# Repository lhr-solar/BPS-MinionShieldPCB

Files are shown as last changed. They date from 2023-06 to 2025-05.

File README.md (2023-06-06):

# BPS-MinionShieldPCB
TODO: Update with useful information

## Components
[Mouser cart]
https://www.mouser.com/ProjectManager/ProjectDetail.aspx?AccessID=0a4c326737

Note: The PADP-24V-1-S connector is not available on mouser, but may be purchased through digikey from this link
https://www.digikey.com/en/products/detail/jst-sales-america-inc/PADP-24V-1-S/1300227

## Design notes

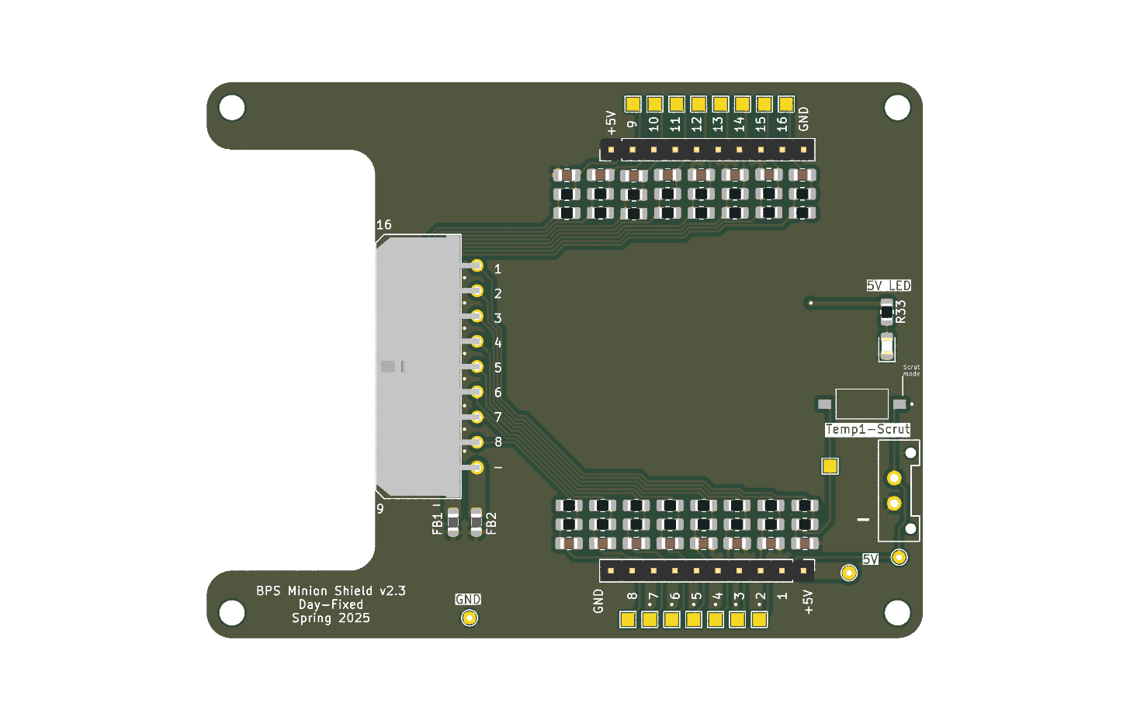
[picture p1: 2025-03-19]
docs/render.png

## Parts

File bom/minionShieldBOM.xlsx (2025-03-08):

Reference | Value | Datasheet | Footprint | Qty | DNP | p/n
C1,C2,C3,C4,C5,C6,C7,C8,C9,C10,C11,C12,C13,C14,C15,C16 | 47nF | https://www.mouser.com/ProductDetail/YAGEO/CC0805JRX7R9BB473?qs=AgBp2OyFlx%252BtTbCMaJ6C1Q%3D%3D | Capacitor_SMD:C_0805_2012Metric_Pad1.18x1.45mm_HandSolder | 16 |  | CC0805JRX7R9BB473
FB1,FB2 | 2.2k | https://www.digikey.com/en/products/detail/laird-signal-integrity-products/HZ0805B222R-10/1236418 | Inductor_SMD:L_0805_2012Metric_Pad1.05x1.20mm_HandSolder | 2 |  | HZ0805B222R-10
J3 | Conn_01x02 | ~ | UTSVT_Connectors:Molex_MicroFit3.0_1x2xP3.00mm_PolarizingPeg_Vertical | 1 |  | 436500227
J4 | Conn_02x09_Counter_Clockwise | ~ | Connector_Molex:Molex_Micro-Fit_3.0_43045-1800_2x09_P3.00mm_Horizontal | 1 |  | 43045-1800
PowerLED1 | Green | https://www.mouser.com/ProductDetail/710-150080VS75000 | LED_SMD:LED_0805_2012Metric_Pad1.15x1.40mm_HandSolder | 1 |  | 150080VS75000
R1,R3,R5,R7,R9,R11,R13,R15,R17,R19,R21,R23,R25,R27,R29,R31 | 4.7k | https://www.mouser.com/ProductDetail/603-RT0805FRE074K7L | Resistor_SMD:R_0805_2012Metric_Pad1.20x1.40mm_HandSolder | 16 |  | RT0805FRE074K7L
R2,R4,R6,R8,R10,R12,R14,R16,R18,R20,R22,R24,R26,R28,R30,R32 | 10k | https://www.mouser.com/ProductDetail/603-RT0805FRE0710KL | Resistor_SMD:R_0805_2012Metric_Pad1.20x1.40mm_HandSolder | 16 |  | RT0805FRE0710KL
R33 | 1.2k | https://www.mouser.com/ProductDetail/603-RT0805FRE071K2L | Resistor_SMD:R_0805_2012Metric_Pad1.20x1.40mm_HandSolder | 1 |  | RT0805FRE071K2L
SW1 | SW_DIP_x01 | ~ | MinionShield:DS04254201BKSMT | 1 |  | DS04-254-2-01BK-SMT

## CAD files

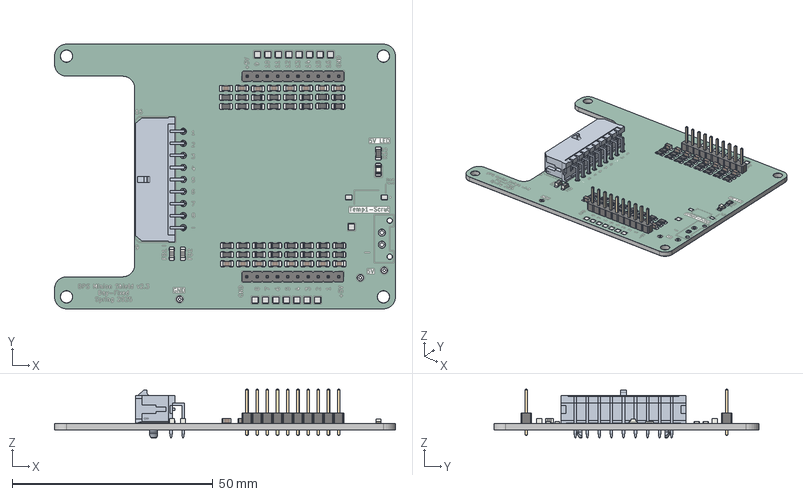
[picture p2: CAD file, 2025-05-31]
docs/renderBoard.step
85.0 x 66.0 x 12.2 mm
PinHeader_1x10_P2.54mm_Vertical x 2
R_0805_2012Metric x 33
C_0805_2012Metric x 16
L_0805_2012Metric x 2
LED_0805_2012Metric
BPS-MinionShield_copper
BPS-MinionShield_pad
BPS-MinionShield_via
BPS-MinionShield_silkscreen
BPS-MinionShield_soldermask
BPS-MinionShield_PCB

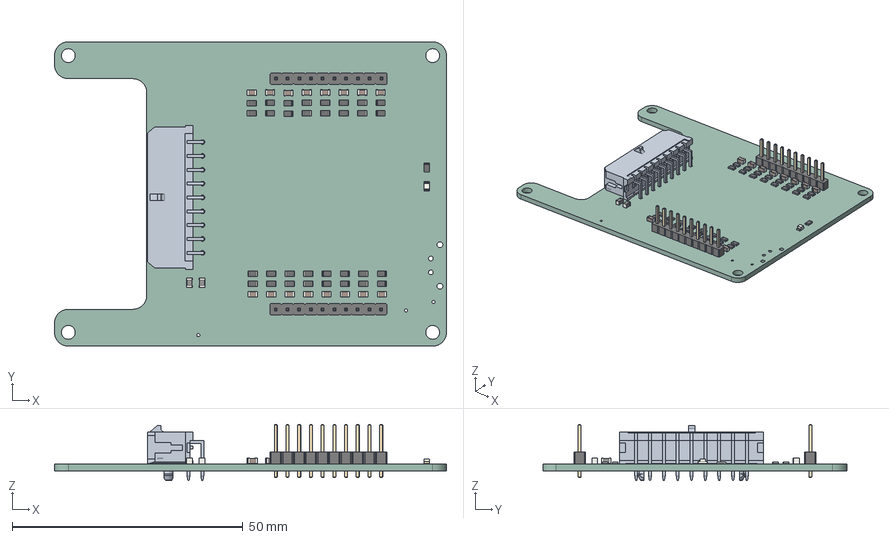
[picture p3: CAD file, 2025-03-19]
docs/board.step
85.0 x 66.0 x 12.2 mm
PinHeader_1x10_P2.54mm_Vertical x 2
R_0805_2012Metric x 33
C_0805_2012Metric x 16
L_0805_2012Metric x 2
LED_0805_2012Metric
BPS-MinionShield_PCB

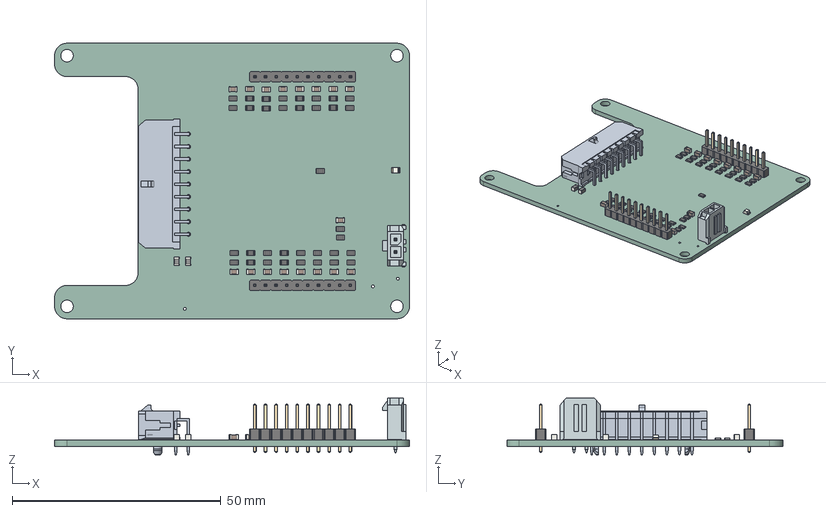
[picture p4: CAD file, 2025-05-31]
minion.step
85.0 x 66.0 x 13.6 mm
PinHeader_1x10_P2.54mm_Vertical x 2
R_0805_2012Metric x 35
C_0805_2012Metric x 17
L_0805_2012Metric x 2
LED_0805_2012Metric
BPS-MinionShield_PCB

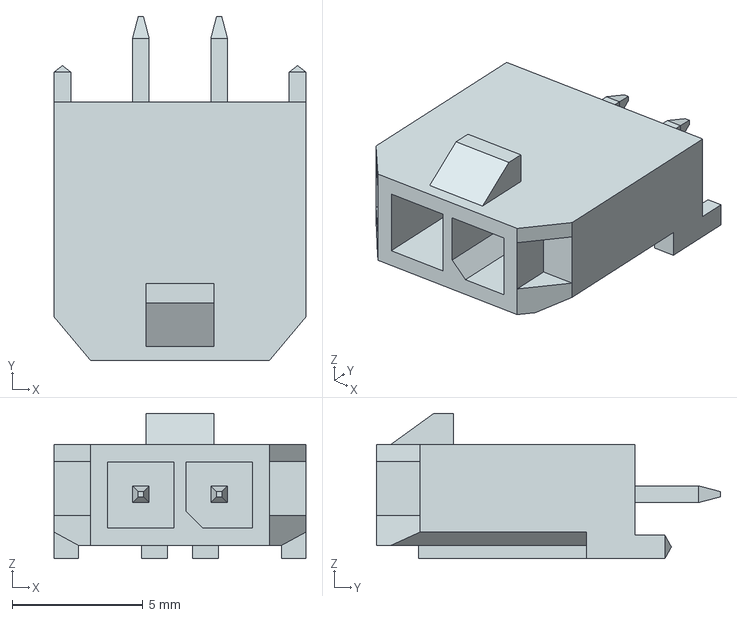
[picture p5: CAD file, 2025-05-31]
436500227.stp
9.65 x 13.2 x 5.57 mm

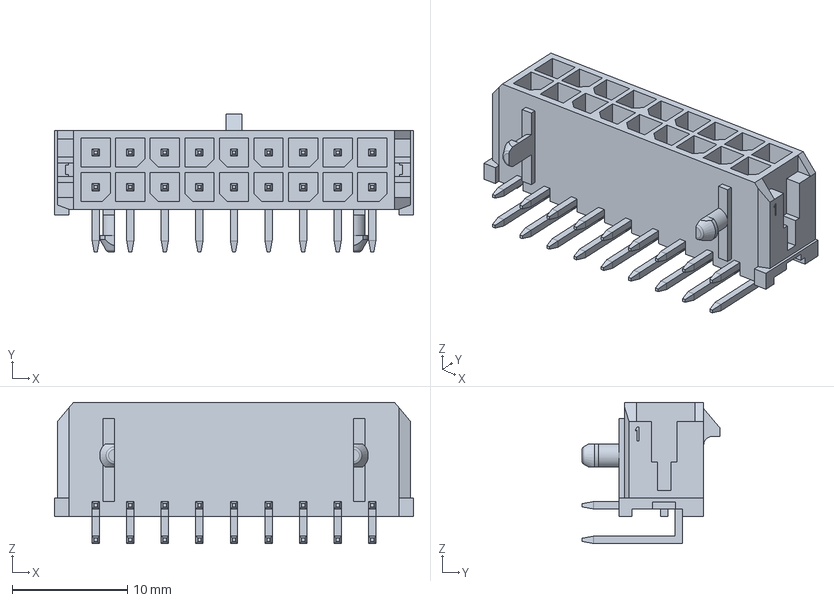
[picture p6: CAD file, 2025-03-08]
0430451800.stp
31.1 x 11.9 x 12.2 mm

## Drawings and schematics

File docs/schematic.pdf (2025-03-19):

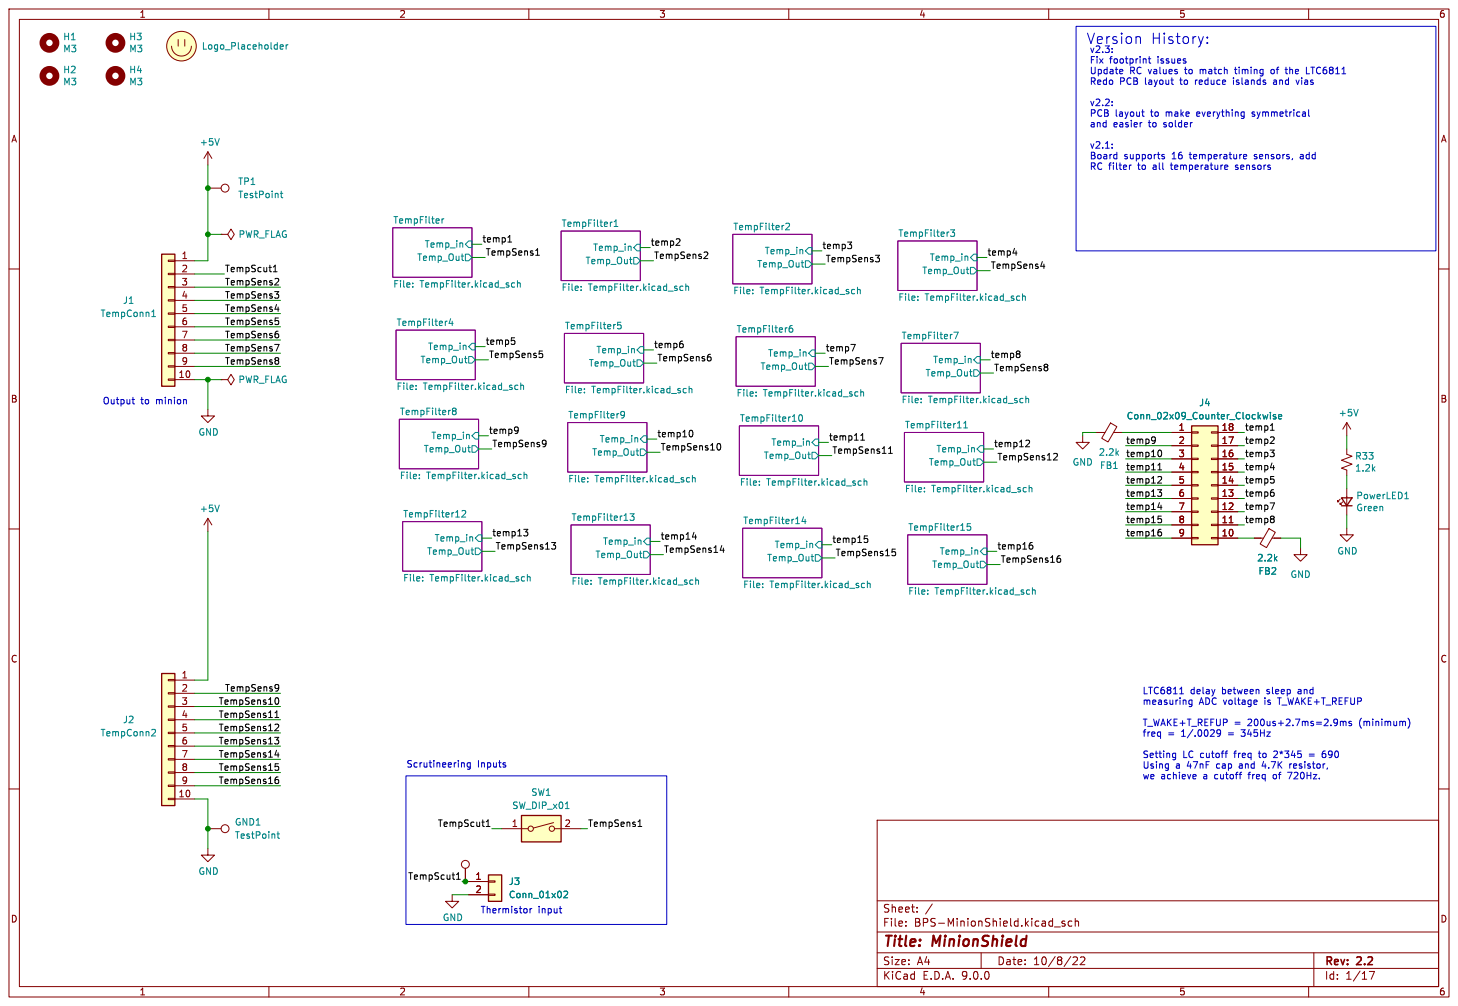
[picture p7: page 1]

File: BPS-MinionShield.kicad_sch Sheet: /
Id: 1/17 Title: MinionShield

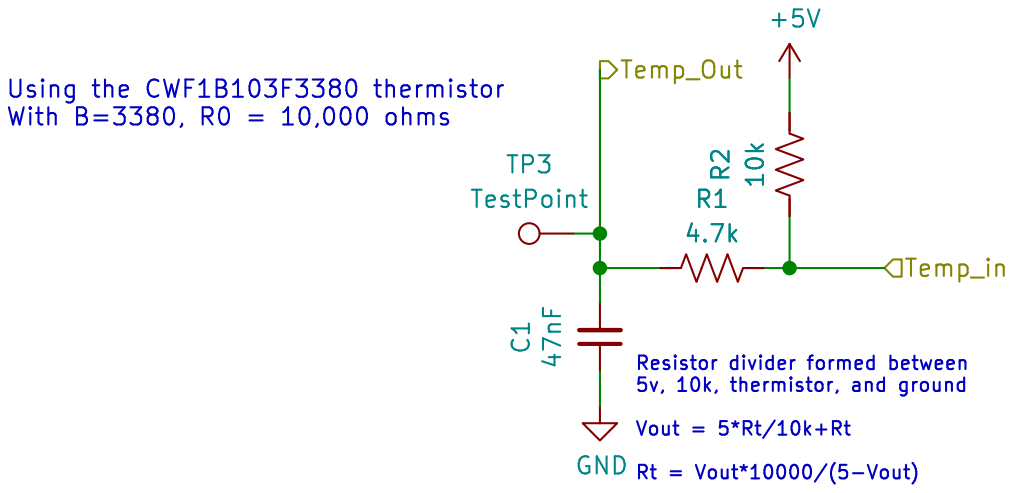
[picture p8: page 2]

Id: 2/17 Title: File: TempFilter.kicad_sch Sheet: /TempFilter/

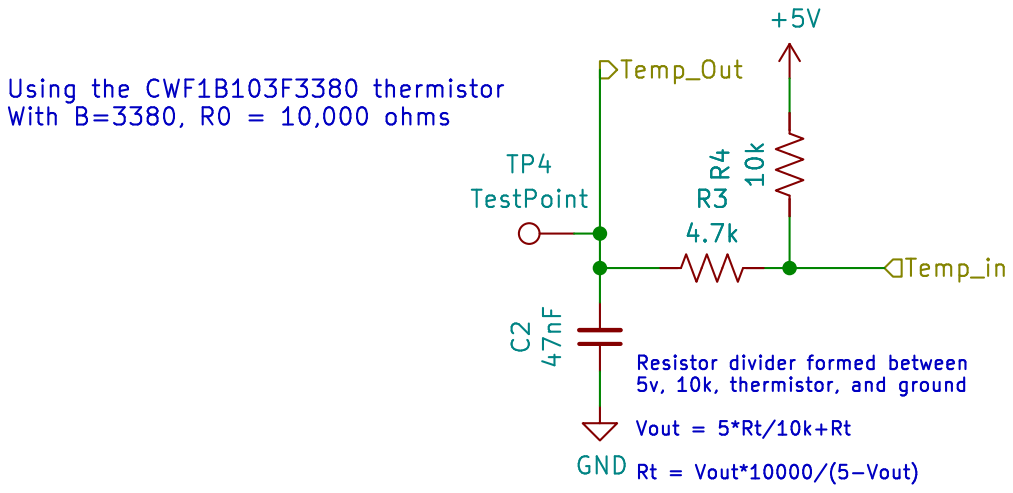
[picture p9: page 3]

Id: 3/17 Title: File: TempFilter.kicad_sch Sheet: /TempFilter1/

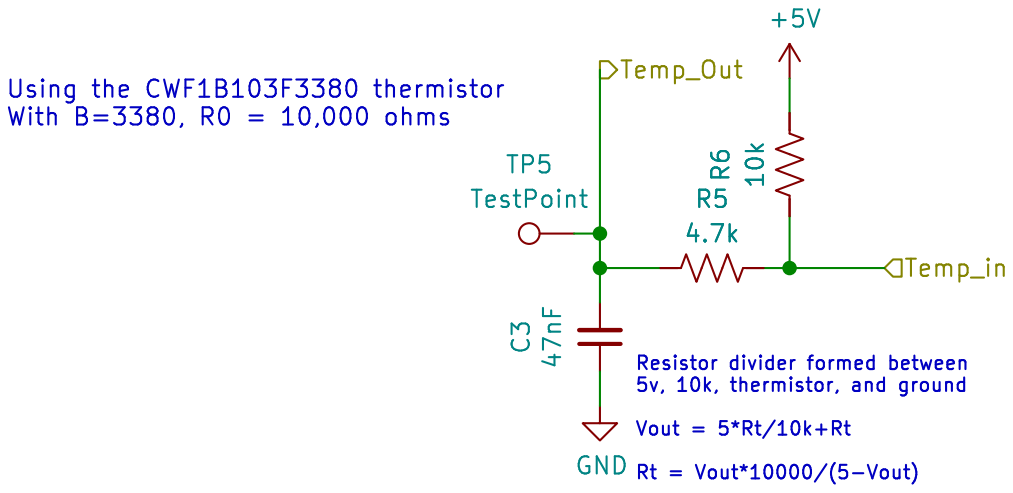
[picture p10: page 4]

Id: 4/17 Title: File: TempFilter.kicad_sch Sheet: /TempFilter2/

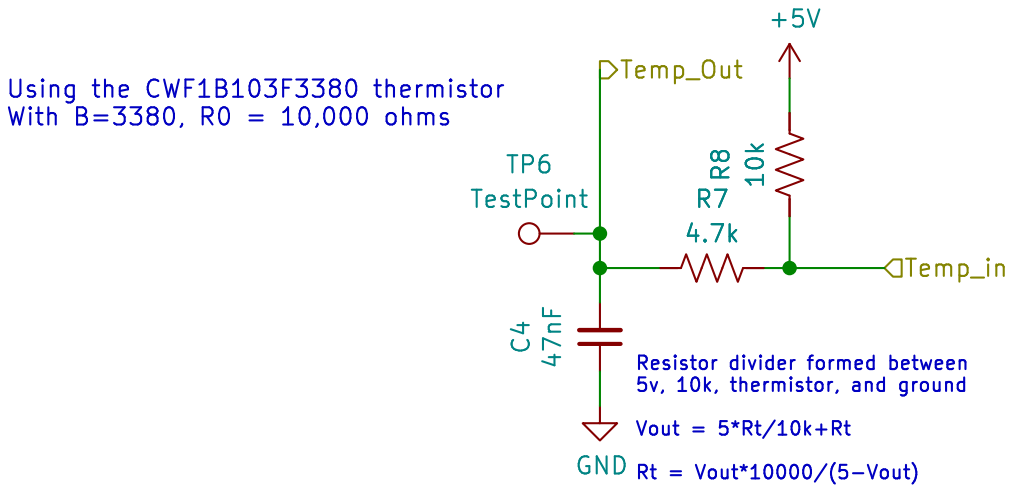
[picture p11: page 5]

Id: 5/17 Title: File: TempFilter.kicad_sch Sheet: /TempFilter3/

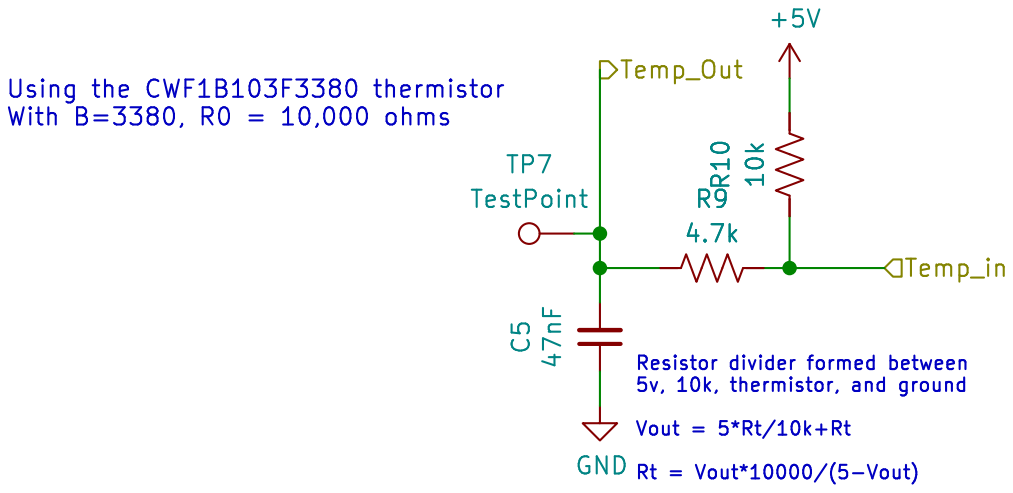
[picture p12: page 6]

Id: 6/17 Title: File: TempFilter.kicad_sch Sheet: /TempFilter4/

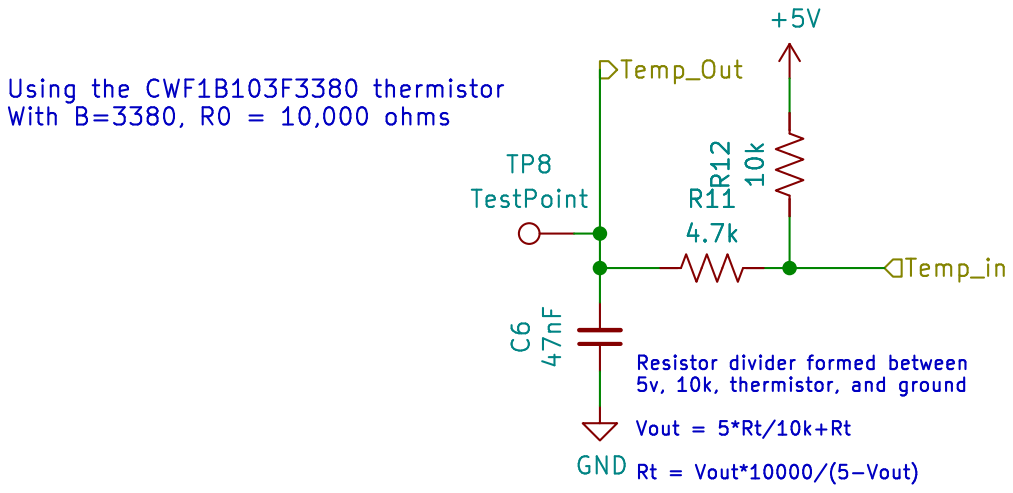
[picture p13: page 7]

Id: 7/17 Title: File: TempFilter.kicad_sch Sheet: /TempFilter5/

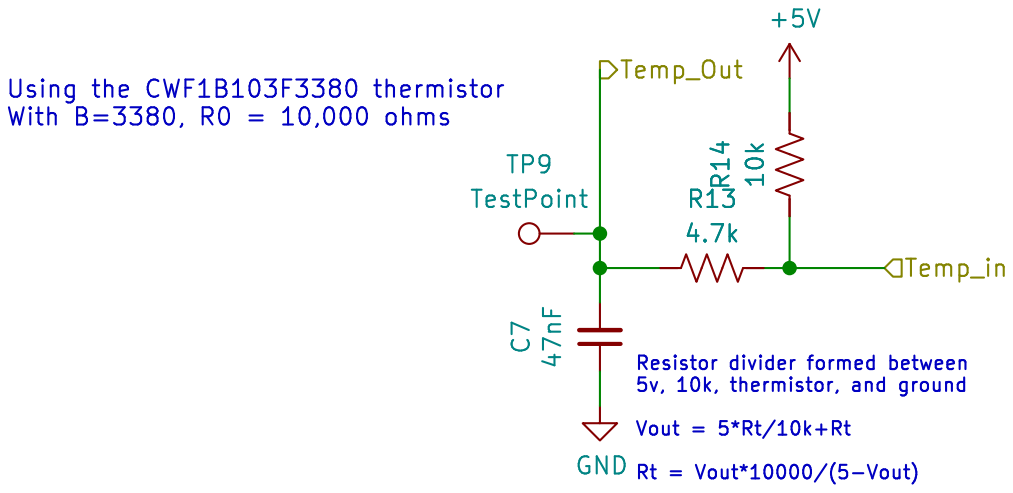
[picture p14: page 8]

Id: 8/17 Title: File: TempFilter.kicad_sch Sheet: /TempFilter6/

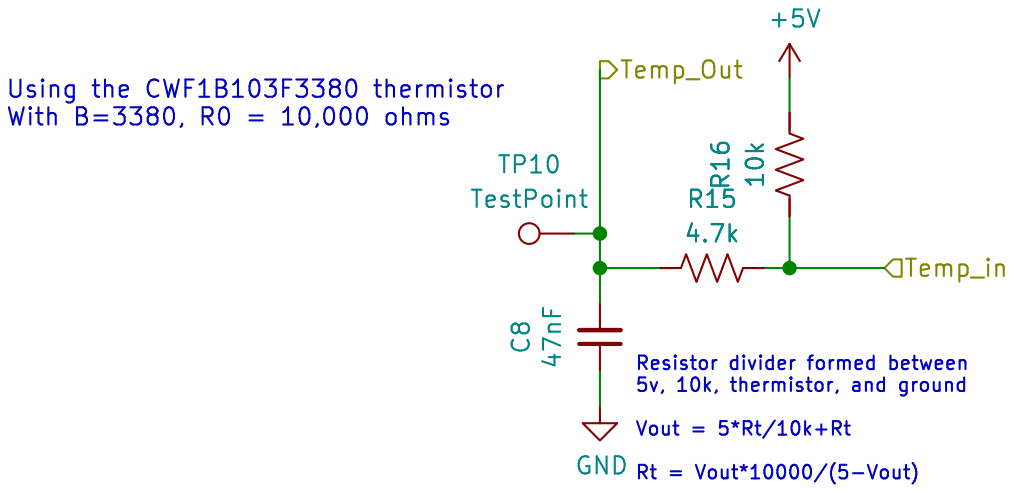
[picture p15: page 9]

Id: 9/17 Title: File: TempFilter.kicad_sch Sheet: /TempFilter7/

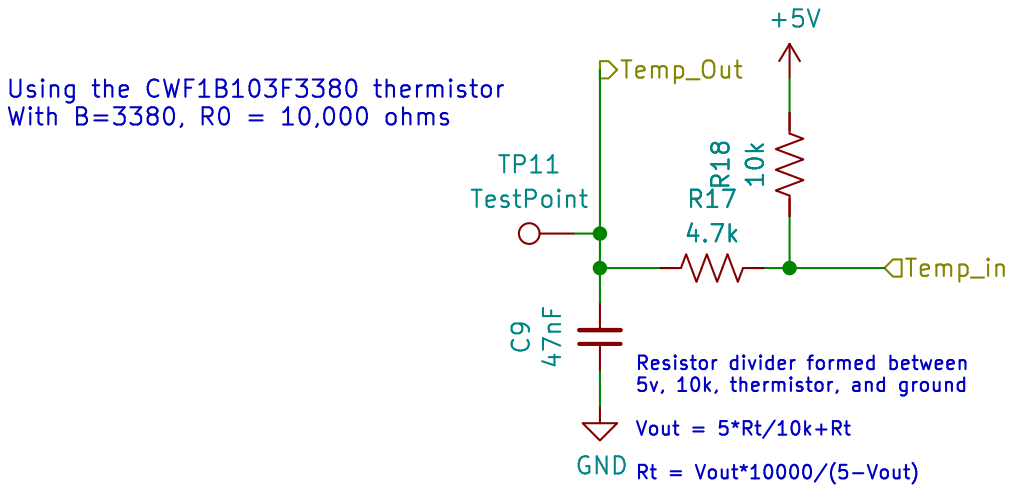
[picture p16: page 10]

Id: 10/17 Title: File: TempFilter.kicad_sch Sheet: /TempFilter8/

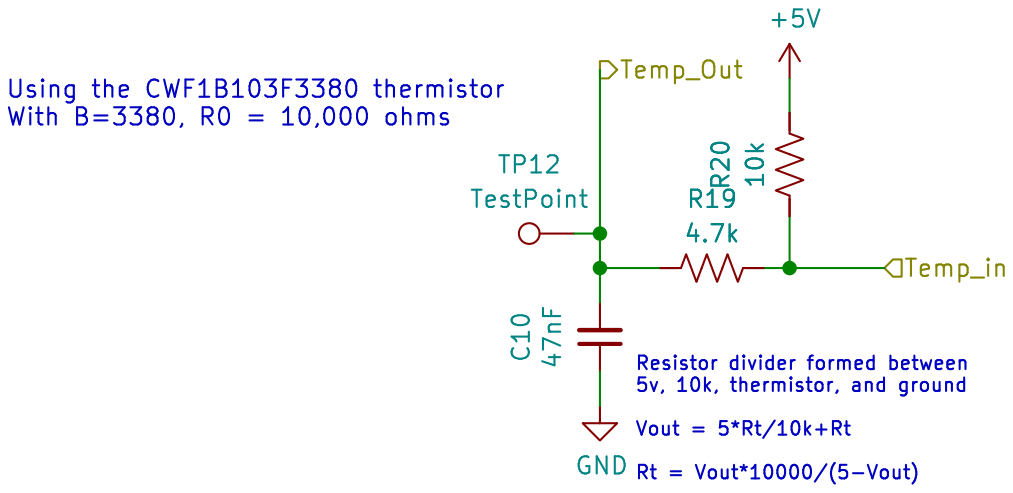
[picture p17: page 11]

Id: 11/17 Title: File: TempFilter.kicad_sch Sheet: /TempFilter9/

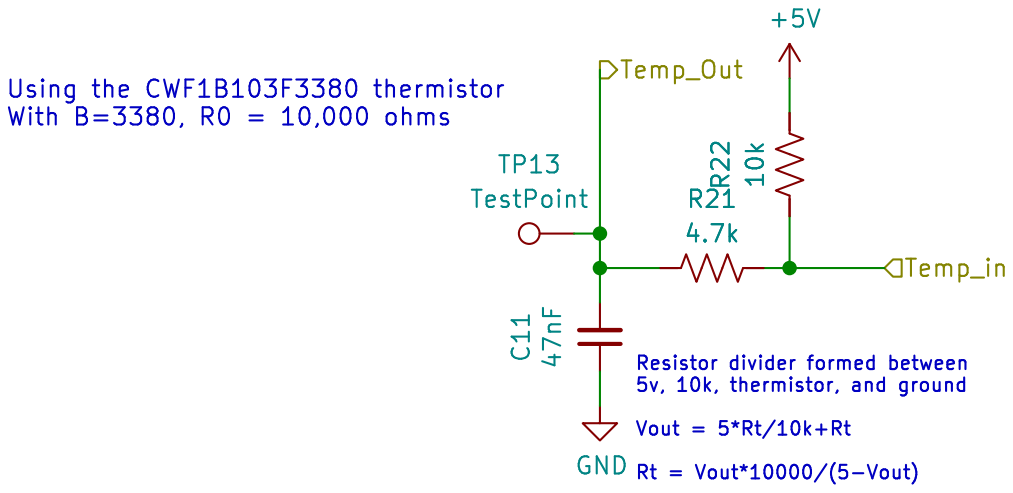
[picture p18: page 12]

Id: 12/17 Title: File: TempFilter.kicad_sch Sheet: /TempFilter10/


Id: 13/17 Title: File: TempFilter.kicad_sch Sheet: /TempFilter11/


Id: 14/17 Title: File: TempFilter.kicad_sch Sheet: /TempFilter12/


Id: 15/17 Title: File: TempFilter.kicad_sch Sheet: /TempFilter13/


Id: 16/17 Title: File: TempFilter.kicad_sch Sheet: /TempFilter14/


Id: 17/17 Title: File: TempFilter.kicad_sch Sheet: /TempFilter15/

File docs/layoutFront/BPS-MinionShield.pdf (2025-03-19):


Id: 1/1 Title: File: BPS-MinionShield.kicad_pcb Sheet: +5V




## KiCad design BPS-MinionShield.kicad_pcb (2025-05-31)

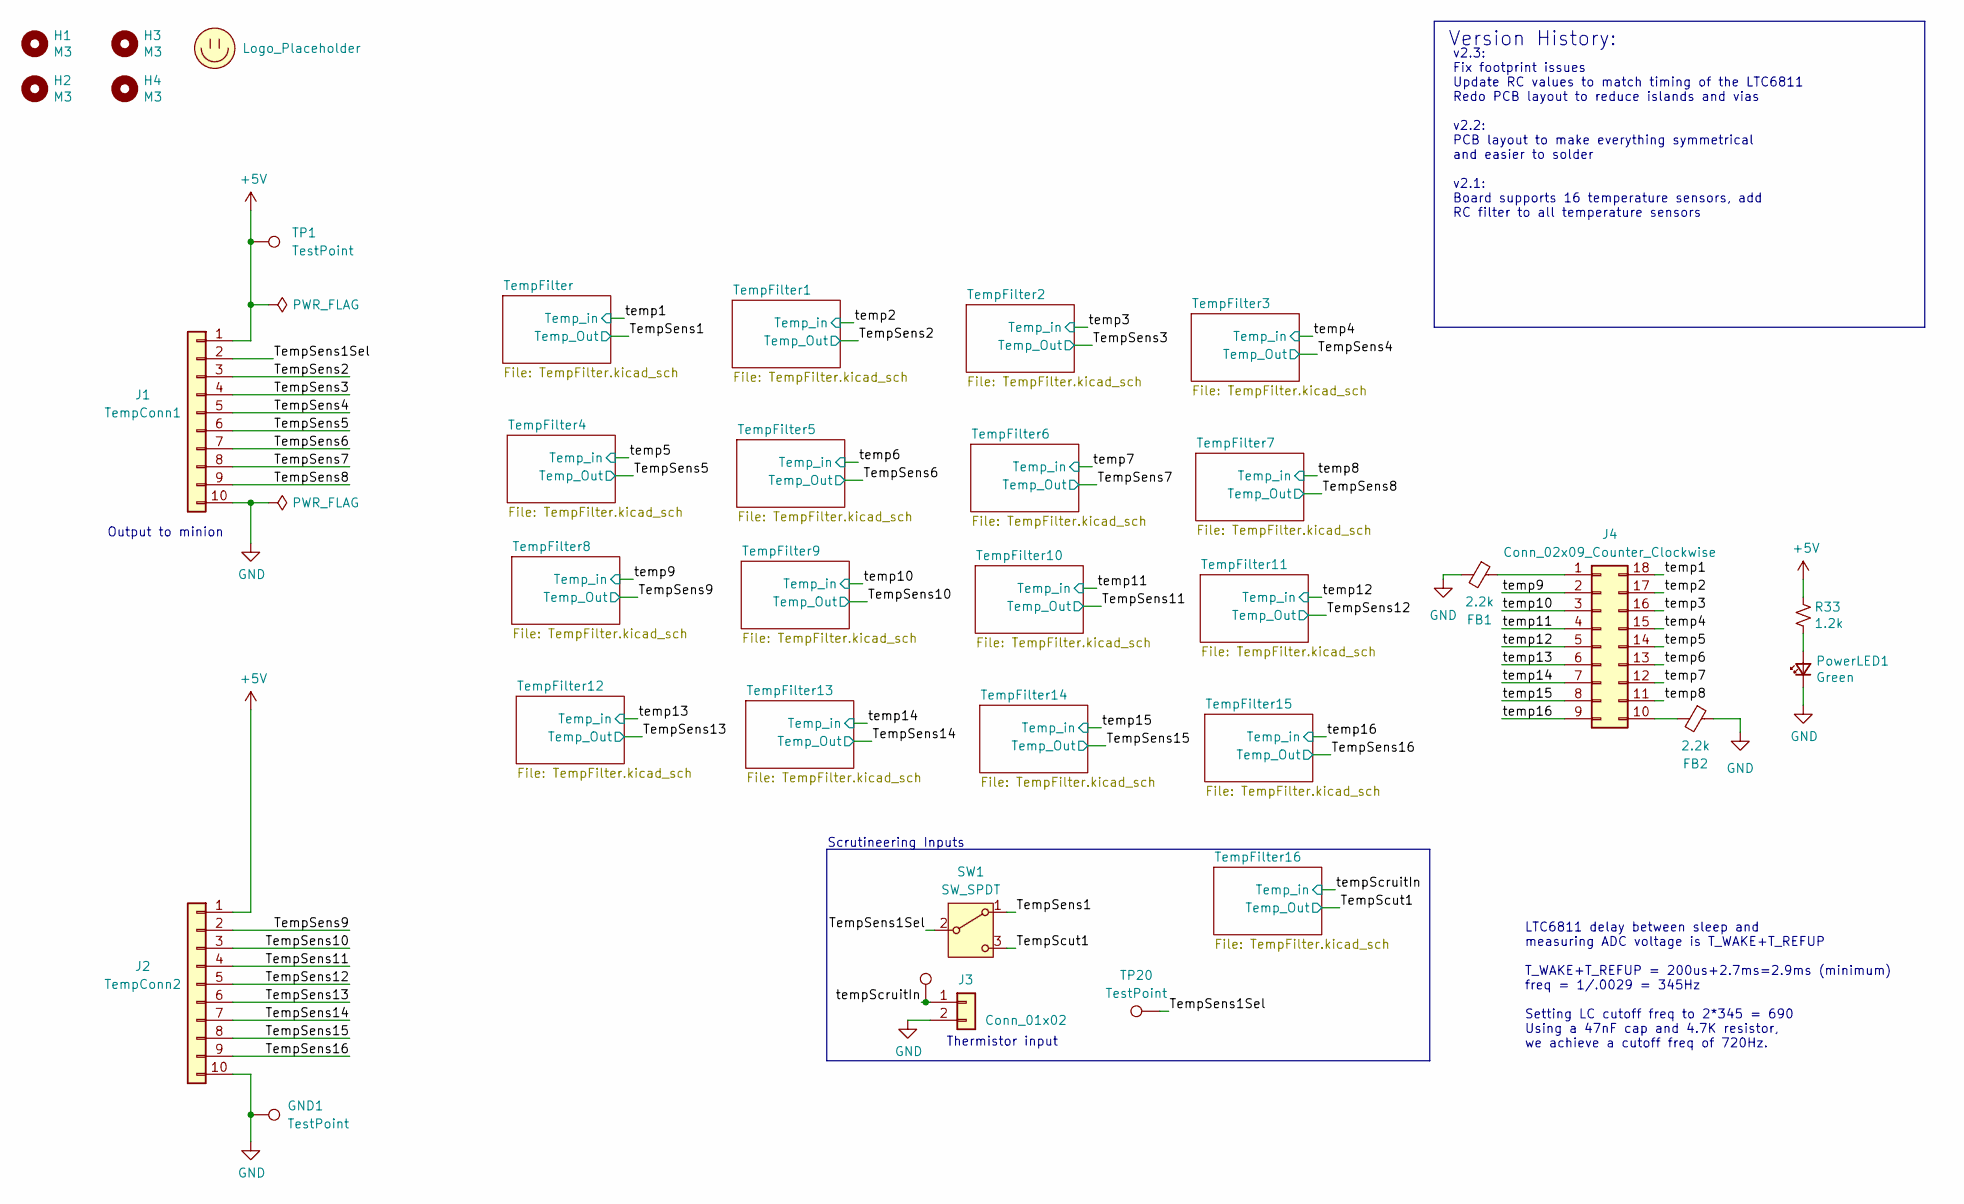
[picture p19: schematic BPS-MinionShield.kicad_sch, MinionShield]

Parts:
FB1, FB2: 2.2k; L_0805_2012Metric_Pad1.05x1.20mm_HandSolder
GND1: TestPoint; TestPoint_THTPad_D1.5mm_Drill0.7mm
H1, H2, H3, H4: M3; MountingHole_3mm
J1: TempConn1; PinHeader_1x10_P2.54mm_Vertical
J2: TempConn2; PinHeader_1x10_P2.54mm_Vertical
J3: Conn_01x02; Molex_MicroFit3.0_1x2xP3.00mm_PolarizingPeg_Vertical
J4: Conn_02x09_Counter_Clockwise; Molex_Micro-Fit_3.0_43045-1800_2x09_P3.00mm_Horizontal
LOGO1: Logo_Placeholder; Hallock_Image_Small
PowerLED1: Green; LED_0805_2012Metric_Pad1.15x1.40mm_HandSolder; LCSC Part # C94741
R33: 1.2k; R_0805_2012Metric_Pad1.20x1.40mm_HandSolder; LCSC Part # C17673
SW1: SW_SPDT; CJS1200TB1
TP1, TP2: TestPoint; TestPoint_THTPad_D1.5mm_Drill0.7mm
TP20: TestPoint; TestPoint_Pad_1.5x1.5mm

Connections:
+5V: J1.1, J2.1, R33.1, TP1.1; also elsewhere on the board
/TempScut1: SW1.3 (C); also elsewhere on the board
/TempSens1: SW1.1 (A); also elsewhere on the board
/TempSens1Sel: J1.2, SW1.2 (B), TP20.1
/TempSens2: J1.3; also elsewhere on the board
/TempSens3: J1.4; also elsewhere on the board
/TempSens4: J1.5; also elsewhere on the board
/TempSens5: J1.6; also elsewhere on the board
/TempSens6: J1.7; also elsewhere on the board
/TempSens7: J1.8; also elsewhere on the board
/TempSens8: J1.9; also elsewhere on the board
/TempSens9: J2.2; also elsewhere on the board
/TempSens10: J2.3; also elsewhere on the board
/TempSens11: J2.4; also elsewhere on the board
/TempSens12: J2.5; also elsewhere on the board
/TempSens13: J2.6; also elsewhere on the board
/TempSens14: J2.7; also elsewhere on the board
/TempSens15: J2.8; also elsewhere on the board
/TempSens16: J2.9; also elsewhere on the board
/temp1: J4.18; also elsewhere on the board
/temp2: J4.17; also elsewhere on the board
/temp3: J4.16; also elsewhere on the board
/temp4: J4.15; also elsewhere on the board
/temp5: J4.14; also elsewhere on the board
/temp6: J4.13; also elsewhere on the board
/temp7: J4.12; also elsewhere on the board
/temp8: J4.11; also elsewhere on the board
/temp9: J4.2; also elsewhere on the board
/temp10: J4.3; also elsewhere on the board
/temp11: J4.4; also elsewhere on the board
/temp12: J4.5; also elsewhere on the board
/temp13: J4.6; also elsewhere on the board
/temp14: J4.7; also elsewhere on the board
/temp15: J4.8; also elsewhere on the board
/temp16: J4.9; also elsewhere on the board
/tempScruitIn: J3.1, TP2.1; also elsewhere on the board
GND: FB1.2, FB2.1, GND1.1, J1.10, J2.10, J3.2, PowerLED1.1 (K); also elsewhere on the board
unnamed: FB1.1, J4.1
unnamed: FB2.2, J4.10
unnamed: PowerLED1.2 (A), R33.2

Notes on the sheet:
Thermistor input
Version History:
v2.3: Fix footprint issues Update RC values to match timing of the LTC6811 Redo PCB layout to reduce islands and vias v2.2: PCB layout to make everything symmetrical and easier to solder v2.1: Board supports 16 temperature sensors, add RC filter to all temperature sensors
Scrutineering Inputs
LTC6811 delay between sleep and measuring ADC voltage is T_WAKE+T_REFUP T_WAKE+T_REFUP = 200us+2.7ms=2.9ms (minimum) freq = 1/.0029 = 345Hz Setting LC cutoff freq to 2*345 = 690 Using a 47nF cap and 4.7K resistor, we achieve a cutoff freq of 720Hz.
Output to minion

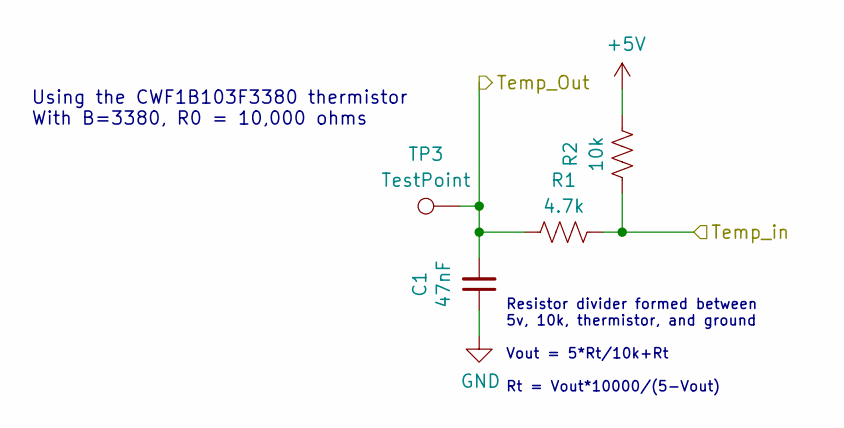
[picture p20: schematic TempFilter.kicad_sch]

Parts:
C1: 47nF; C_0805_2012Metric_Pad1.18x1.45mm_HandSolder; LCSC Part # C1745
R1: 4.7k; R_0805_2012Metric_Pad1.20x1.40mm_HandSolder; LCSC Part # C17673
R2: 10k; R_0805_2012Metric_Pad1.20x1.40mm_HandSolder; LCSC Part # C17414
TP3: TestPoint; TestPoint_Pad_1.5x1.5mm

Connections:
+5V: R2.2; also elsewhere on the board
/TempSens1: C1.2, R1.1, TP3.1; also elsewhere on the board
/temp1: R1.2, R2.1; also elsewhere on the board
GND: C1.1; also elsewhere on the board

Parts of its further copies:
C2, C3, C4, C5, C6, C7, C8, C9, C10, C11, C12, C13, C14, C15, C16, C17: 47nF; C_0805_2012Metric_Pad1.18x1.45mm_HandSolder; LCSC Part # C1745
R3, R5, R7, R9, R11, R13, R15, R17, R19, R21, R23, R25, R27, R29, R31, R34: 4.7k; R_0805_2012Metric_Pad1.20x1.40mm_HandSolder; LCSC Part # C17673
R4, R6, R8, R10, R12, R14, R16, R18, R20, R22, R24, R26, R28, R30, R32, R35: 10k; R_0805_2012Metric_Pad1.20x1.40mm_HandSolder; LCSC Part # C17414
TP4, TP5, TP6, TP7, TP8, TP9, TP10, TP11, TP12, TP13, TP14, TP15, TP16, TP17, TP18, TP19: TestPoint; TestPoint_Pad_1.5x1.5mm

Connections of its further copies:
+5V: R4.2, R6.2, R8.2, R10.2, R12.2, R14.2, R16.2, R18.2, R20.2, R22.2, R24.2, R26.2, R28.2, R30.2, R32.2, R35.2; also elsewhere on the board
/TempScut1: C17.2, R34.1, TP19.1; also elsewhere on the board
/TempSens2: C2.2, R3.1, TP4.1; also elsewhere on the board
/TempSens3: C3.2, R5.1, TP5.1; also elsewhere on the board
/TempSens4: C4.2, R7.1, TP6.1; also elsewhere on the board
/TempSens5: C5.2, R9.1, TP7.1; also elsewhere on the board
/TempSens6: C6.2, R11.1, TP8.1; also elsewhere on the board
/TempSens7: C7.2, R13.1, TP9.1; also elsewhere on the board
/TempSens8: C8.2, R15.1, TP10.1; also elsewhere on the board
/TempSens9: C9.2, R17.1, TP11.1; also elsewhere on the board
/TempSens10: C10.2, R19.1, TP12.1; also elsewhere on the board
/TempSens11: C11.2, R21.1, TP13.1; also elsewhere on the board
/TempSens12: C12.2, R23.1, TP14.1; also elsewhere on the board
/TempSens13: C13.2, R25.1, TP15.1; also elsewhere on the board
/TempSens14: C14.2, R27.1, TP16.1; also elsewhere on the board
/TempSens15: C15.2, R29.1, TP17.1; also elsewhere on the board
/TempSens16: C16.2, R31.1, TP18.1; also elsewhere on the board
/temp2: R3.2, R4.1; also elsewhere on the board
/temp3: R5.2, R6.1; also elsewhere on the board
/temp4: R7.2, R8.1; also elsewhere on the board
/temp5: R9.2, R10.1; also elsewhere on the board
/temp6: R11.2, R12.1; also elsewhere on the board
/temp7: R13.2, R14.1; also elsewhere on the board
/temp8: R15.2, R16.1; also elsewhere on the board
/temp9: R17.2, R18.1; also elsewhere on the board
/temp10: R19.2, R20.1; also elsewhere on the board
/temp11: R21.2, R22.1; also elsewhere on the board
/temp12: R23.2, R24.1; also elsewhere on the board
/temp13: R25.2, R26.1; also elsewhere on the board
/temp14: R27.2, R28.1; also elsewhere on the board
/temp15: R29.2, R30.1; also elsewhere on the board
/temp16: R31.2, R32.1; also elsewhere on the board
/tempScruitIn: R34.2, R35.1; also elsewhere on the board
GND: C2.1, C3.1, C4.1, C5.1, C6.1, C7.1, C8.1, C9.1, C10.1, C11.1, C12.1, C13.1, C14.1, C15.1, C16.1, C17.1; also elsewhere on the board

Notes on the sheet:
Using the CWF1B103F3380 thermistor With B=3380, R0 = 10,000 ohms
Resistor divider formed between 5v, 10k, thermistor, and ground Vout = 5*Rt/10k+Rt Rt = Vout*10000/(5-Vout)

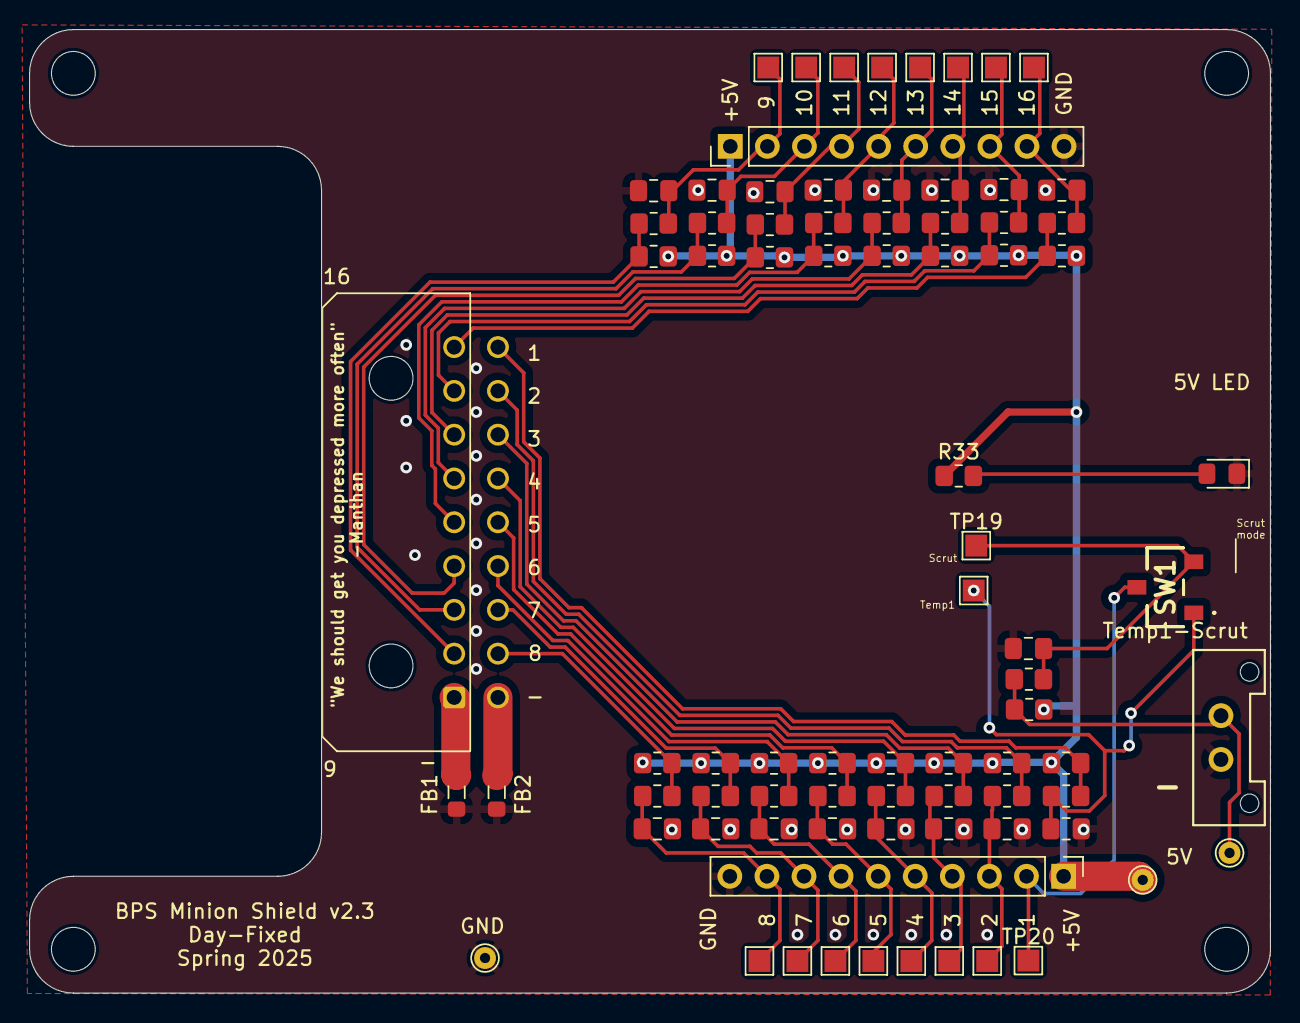
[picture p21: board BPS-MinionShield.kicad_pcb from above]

Board: 2 copper layers, 85.0 x 66.0 mm, 86 parts (1 on the bottom side), 40 nets.

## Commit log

2020-08-16 Adds BPS Minion Shield kicad project
    [BPS-MinionShieldPCB.kicad_pcb, BPS-MinionShieldPCB.sch]
2020-08-16 Adds documentation files and submodules
    [BPS-MinionShieldPCB.kicad_pcb]
2020-09-01 Renames project to not include PCB
    [BPS-MinionShield.kicad_pcb, BPS-MinionShield.sch]
2022-09-23 Added RC filter to all temperature sensors
    [BPS-MinionShield.kicad_sch]
2022-09-24 added ferrite beads, datasheets, and footprints
    [BPS-MinionShield.kicad_sch]
2022-09-26 made capacitors pretty
    [BPS-MinionShield.kicad_sch]
2022-10-01 generated bom
    [BPS-MinionShield.kicad_sch]
2022-10-01 added thermistor detail
    [BPS-MinionShield.kicad_sch]
2022-10-08 added tvs diodes
    [BPS-MinionShield.kicad_sch]
2022-10-16 finished PCB layout with a displayport connector for thermistors
    [BPS-MinionShield.kicad_pcb, BPS-MinionShield.kicad_sch]
2022-10-22 added orion connector footprint
    [BPS-MinionShield.kicad_pcb, BPS-MinionShield.kicad_sch]
2022-10-29 new footprint from temp expansion module
    [BPS-MinionShield.kicad_pcb, BPS-MinionShield.kicad_sch]
2022-11-05 pcb routing done
    [BPS-MinionShield.kicad_pcb]
2022-11-12 made stuff pretty and rerouted
    [BPS-MinionShield.kicad_pcb, BPS-MinionShield.kicad_sch]
2022-11-19 redid the vias
    [BPS-MinionShield.kicad_pcb, BPS-MinionShield.kicad_sch]
2022-11-28 rerouted and added Dr. Hallock photo
    [BPS-MinionShield.kicad_pcb]
2022-12-03 generated mouser cart and gerber files
    [BPS-MinionShield.kicad_pcb, oldpcb.kicad_pcb]
2022-12-03 actually added gerber files
    [BPS-MinionShield-B_Cu.gbl, BPS-MinionShield-B_Mask.gbs, BPS-MinionShield-B_Silkscreen.gbo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]
2022-12-03 removed some gnd test points
    [BPS-MinionShield-B_Cu.gbl, BPS-MinionShield-B_Mask.gbs, BPS-MinionShield-B_Silkscreen.gbo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]
2022-12-07 implemented hannah changes and added personalization
    [BPS-MinionShield-B_Cu.gbl, BPS-MinionShield-B_Mask.gbs, BPS-MinionShield-B_Silkscreen.gbo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]
2022-12-16 keep just 1 gnd testpoint
    [BPS-MinionShield.kicad_pcb, BPS-MinionShield.kicad_sch]
2022-12-26 fix connector footprint, change quotes
    [BPS-MinionShield-B_Cu.gbl, BPS-MinionShield-B_Mask.gbs, BPS-MinionShield-B_Silkscreen.gbo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]
2023-01-21 add PADP-24 connector to submodule
2023-01-21 fix footprints and reference designators
    [BPS-MinionShield.kicad_pcb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]
2023-01-25 update connector from digikey
2023-02-06 change to all passives to 0805 footprints
    [BPS-MinionShield-B_Cu.gbl, BPS-MinionShield-B_Mask.gbs, BPS-MinionShield-B_Silkscreen.gbo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]
2023-02-25 move ferrite beads for more space
    [BPS-MinionShield-B_Cu.gbl, BPS-MinionShield-B_Mask.gbs, BPS-MinionShield-B_Silkscreen.gbo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]
2023-02-25 Revert "update connector from digikey"
    This reverts commit 7205807fa5bedf384e424ba98877d198a6dc1d85.
2023-02-25 Revert "move ferrite beads for more space"
    This reverts commit 10398d522d6bd349285b691c333d995223f13479.
    [BPS-MinionShield-B_Cu.gbl, BPS-MinionShield-B_Mask.gbs, BPS-MinionShield-B_Silkscreen.gbo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]
2023-02-27 move ferrite beads away from connector
    [BPS-MinionShield-B_Cu.gbl, BPS-MinionShield-B_Mask.gbs, BPS-MinionShield-B_Silkscreen.gbo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]
2023-05-19 fix some islands
    [BPS-MinionShield.kicad_pcb]
2023-05-19 change cap values to 100nf
    [BPS-MinionShield.kicad_pcb, BPS-MinionShield.kicad_sch]
2023-05-21 address maestro tianda's review
    [BPS-MinionShield.kicad_pcb]
2023-05-25 address all tianda requests, start standardization
    [BPS-MinionShield.kicad_pcb, BPS-MinionShield.kicad_sch]
2023-06-04 address manthan changes, finalize PR
    [BPS-MinionShield-B_Cu.gbl, BPS-MinionShield-B_Mask.gbs, BPS-MinionShield-B_Silkscreen.gbo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]
2023-06-06 make vias more pretty
    [BPS-MinionShield-B_Cu.gbl, BPS-MinionShield-B_Mask.gbs, BPS-MinionShield-B_Silkscreen.gbo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]
2023-11-15 Fixed gerbers
    [BPS-MinionShield-B_Cu.gbl, BPS-MinionShield-B_Mask.gbs, BPS-MinionShield-B_Silkscreen.gbo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]
2025-03-07 started reworking hat
    [430451812.stp, BPS-MinionShield.kicad_pcb, BPS-MinionShield.kicad_sch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]
2025-03-08 board done
    [BPS-MinionShield-B_Cu.gbl, BPS-MinionShield-B_Mask.gbs, BPS-MinionShield-B_Silkscreen.gbo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]
2025-03-09 step files
    [BPS-MinionShield.step]
2025-03-16 update for standardization
    [BPS-MinionShield.kicad_pcb, BPS-MinionShield.kicad_sch, TempFilter.kicad_sch]
2025-03-17 move to minion shield
    [BPS-MinionShield.kicad_pcb, BPS-MinionShield.kicad_sch, BPS-MinionShield.step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]
2025-03-18 testing with new library
    [board.step]
